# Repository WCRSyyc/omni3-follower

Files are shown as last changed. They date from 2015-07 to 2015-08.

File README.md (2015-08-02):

# 3 Omni Wheel line follower

Arduino sketch code for a 3 [Omni Wheel](https://en.wikipedia.org/wiki/Omni_Wheel) (also called Poly Wheel) based line follower robot.

The physical structure for the robot chassis is based on an equalateral triangle base, with a single wheel on each edge
The electronics are mounted on (somewhat smaller) triangular layers above the main base, and a bottom layer is hung
below the main chasis to hold the line follower sensors just above the floor.  The points of the chassis layer are
truncated, turning it into a six sided shape, with 3 long and 3 shorter edges.  Currently the bottom sensor layer is cut
to the same shape and size as the chassis layer, but it really only needs to be large enough to hold the circle of
downward sensors.  The mount points could be moved inside of the sensor circle.

This layout is more robust to variations in the driving surface than the [four omni wheel](https://github.com/WCRSyyc/omni4-follower)
robot.  With only 3 contact points, it can tilt to match surface contours, and maintain contact and traction on all wheels.

Spreadsheets are included in .xls and .ods formats with position and dimension information for the base and sensor levels.  A .dxf of file is also included, that was created from the spreadsheet information, then used to laser-cut the pieces.

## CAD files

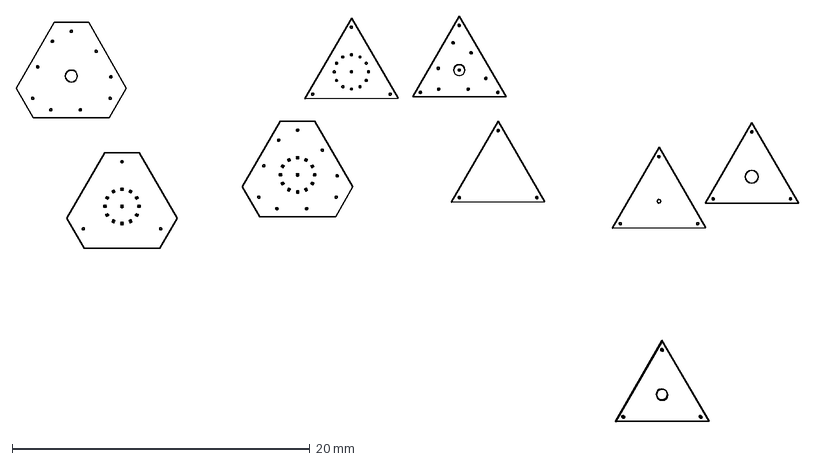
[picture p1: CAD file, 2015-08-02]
LineFollowerTemplates-Triangle.dxf
52.5 x 27.2 mm

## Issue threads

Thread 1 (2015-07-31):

Refactoring idea: separate the sensing and control logic

mMerlin, 2015-07-31:
The line follower has 2 quite distinct functional modules.  One reads the sensors to determine where the line is, and the other sends commands to the motors (servos) to move in the correct direction.  The functions have minimal overlap, and it should be possible to make them into modules or libraries.  This would make it easy to plug-and-play with different physical chassis configuration, and alternate sensor packages.

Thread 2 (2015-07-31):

Line following 'logic'

mMerlin, 2015-07-31:
A more **usual** line follower bot, with all of the sensors at the front, tends to start turning as soon as the line being followed moves off of center.  Or deliberately keeps turning back and forth to *sniff* for the edges of the line.  With the circle of sensors being used for this project, an alternative strategy might be more appropriate.  Whether it can be implemented or not is a separate issue to be explored :)

To start, I will define the line following goal to be to keep the sensor at the centre of the circle over the line.  That means the changes in direction can / need to be delayed from the time that the leading edge sensors detect the line moving away from the current direction of travel.  I say `line moving`, because from the perspective of the bot, and controlling code, that is what is happening.  The line **moves** away from the sensor that was detecting it, and the bot will need to *follow* the moving line.

With a straight line, and the bot aligned with, and centered over it, 3 sensors should see the line.  The middle point, plus one front (direction of travel) and one back sensor.  If the line stays straight, and the bot starts to stray from the line, the front sensor will loose the line, but the other 2 will still see it.  Same thing if the line curves, or does a shape bend.  The middle and back sensors will continue to see the line, when the leading sensor looses 'contact'.  With the goal of keeping the middle sensor on the line, no action is needed immediately for any of those cases.  The bot can maintain the current course, and wait to see where / how fast the line position is changing.  Only when the bots motion (based on known (although approximate) speed) brings it to the place where the middle sensor reaches (or almost reaches) the point where the leading sensor lost the line is a correction needed.  By that time, additional sensor readings should have provided enough information to make a pretty good guess at the local shape of the line.  This should allow accurate sharp turns that keep the middle sensor on the line.  It should also allow smoothly following a curved line, instead of continuously 'bouncing' off of the edges of the line.

Information that will need to be determined before implementation: For any direction of travel, how fast is the bot moving?  How fast can it change direction?  That is really, what does the acceleration look like for radical changes (90 degrees or more turn, maximum speed to 0 and back)?  Unless the acceleration is high enough to have a  negligible effect on positioning (relative to the errors from sensor measurements, and position uncertainty (relative to the line), that will need to be accounted for in the turn calculations.  It might even need explicit deceleration for sharp corners.

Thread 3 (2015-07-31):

Fails figure 8 line pattern

mMerlin, 2015-07-31:
The current code ends up following only one loop of the figure 8, instead of crossing over and following other loop.  At least somewhat dependent on the starting conditions.  The initial test correctly crossed the line intersection, but when it came around to the intersection again, it just circled on loop on that side.

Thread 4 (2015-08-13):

Interaction between power source and servo control on Mega

mMerlin, 2015-08-13:
Well that was interesting/frustrating/different.  There seems to be some sort of interaction between what power source is used for the Mega2560 and servo control.

This **should** not be a servo power problem for (at least) 2 reasons.
1) in both cases the servos are powered through a separate power regulator
2) half of the servo range works, and the other half should need the same power

I was setting up to do some calibration / profiling of the servos for the line follower for the museum display, and was getting strange results.  So I wrote a new test script that just exercises the servos based on the Sweep example sketch.  That did not work either, so I reloaded the original line-follower sketched, and tried that with the test track.  That worked normally.  Finally I tried my test sketch powered by the on board regulator instead of through the usb cable.  That seemed to work, but of course no debug output without the usb cable and Serial.print().  So I cut my test program down even more to make sure Serial was not causing the problem.  Same symptoms.  Powered by USB only the low range servo.write() worked.  The high value (180) acts about the same as 90.

Summary: With the Mega hooked up (only) to, and powered by, a usb cable, only Servo.write() 0 through 90 seems to be working correctly.  Higher values act about like 90, or jitter, or turn the servo very slowly in the opposite direction (from the low values).  When the usb cable is removed, and the Mega is powered through the on board regulator, the full range of servo.write() works.  I also tested using servo.writeMicroseconds() with the same results.  Only the lower half of the range works when powered through usb.

I have minimal tools at home.  If we get time on Saturday, I'll see about putting a scope on some of the voltages/signals, to see if there is an obvious difference.

I’m open to ideas about what could cause the observed symptoms.

For reference, here is the simple test sketch with everything deliberately hard-coded. write(180) does not work (only) when powered through usb.
```c
void setup()
{
  // Serial.begin(9600);
  myservoA.attach(22);
  myservoB.attach(23);
  myservoC.attach(24);
  myservoA.write(90);
  myservoB.write(90);
  myservoC.write(90);
}

void loop()
{
  // Serial.println("full forward");
  myservoA.write(180);
  myservoB.write(180);
  myservoC.write(180);
  delay(5000);
  myservoA.write(90);
  myservoB.write(90);
  myservoC.write(90);
  delay(1000);
  // Serial.println("full backward");
  myservoA.write(0);
  myservoB.write(0);
  myservoC.write(0);
  delay(5000);
  myservoA.write(90);
  myservoB.write(90);
  myservoC.write(90);
  delay(1000);
}
```

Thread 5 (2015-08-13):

servo profiling

mMerlin, 2015-08-13:
If the previous issue #4 can not be resolved, and alternate method of collecting the profile information is needed.  The current physical build of the line follower does not have any way of directly reporting information without a usb cable.

## Ideas
* Connected another Arduino board, and setup a serial pass-thru sketch, So the mega can use Serial.print to send to the 2nd board, which echos the content to its on usb connected serial line.
* The bot has 13 LED's for displaying sensor / status information.  13 bits is enough to report settings and timing results.
* The servo rotation sensor can be attached to the second Arduino board, and the timing done there.  That was actually the way the initial testing (of the rotation sensor) was done.  This would need a way to control the state (servo speed) changes on the Mega.  That could (again) be a direct serial connection, but even a single digital pin would be enough to cycle through the states

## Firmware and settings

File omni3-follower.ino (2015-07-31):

//  Line_Follower_Display_Tripod_150725

//  Direction coordinates in Direction subroutine programmed according to paper obtained at this site:
//  http://www.researchgate.net/publication/228786543_Three_omni-directional_wheels_control_on_a_mobile_robot
//  Some fine tuning was required, due to differences between the three servos

#define SIZE 14
#define CUTOFF 150
#include <Servo.h>
Servo myservoA; 
Servo myservoB;  
Servo myservoC;
int TRUE = HIGH;
int FALSE = LOW;
int black;
int blacks = 0;
int CENTER = 13;
int find = 0;
int i = 0;
int inside = 0;
int loops = 0;
int outside = 0;
int STOP = 15;
int quit = FALSE;
long time;
long time0;
int ledPins[SIZE] = {0,31,32,33,34,35,36,37,38,39,40,41,42,43};
int lightLevel[SIZE] = {0,1,2,3,4,5,6,7,8,9,10,11,12,13};
int list[37] = {0,1,2,3,4,5,6,7,8,9,10,11,12,1,2,3,4,5,6,7,8,9,10,11,12,1,2,3,4,5,6,7,8,9,10,11,12};

void setup() {
  Serial.begin(9600);
  myservoA.attach(22);  
  myservoB.attach(23);
  myservoC.attach(24);
  Direction(STOP);
  for (int i = 1; i < SIZE; i++) {
    pinMode(lightLevel[i], INPUT);
    pinMode(ledPins[i], OUTPUT);
    digitalWrite(ledPins[i], LOW);
  }
  for (int i = 1; i < 4; i++) {
    digitalWrite(ledPins[1], HIGH);
    delay (200);
    digitalWrite(ledPins[1], LOW);
    delay (200);
  }
  digitalWrite(ledPins[1], HIGH);
  delay (3000);
  scan();
  time = millis();
  Serial.println(" ");
  Serial.println ("Point 0 - start");
  Serial.print("time = ");
  Serial.println(time);
  sensors ();
  //
  // find start point
  //
  find = 0;
  time0 = millis();
  do {
    Direction(4);
    if (analogRead(CENTER) > CUTOFF && find == 0) {
      find = 1;
    }
    else if (analogRead(CENTER) < CUTOFF && find == 1) {
      find = 2;
      i = 1;
    }
  }
  while (find != 2 && millis() - time0 < 3000);
  if (find !=2){
    find = 0;
    do {
      Direction(10);
      if (analogRead(CENTER) > CUTOFF && find == 0) {
        find = 1;
      }
      else if (analogRead(CENTER) < CUTOFF && find == 1) {
        find = 2;
        i = 7;
      }
    }
    while (find != 2);
  }
  Direction(STOP);
  delay(5);
  Serial.println (" ");
  Serial.println("Point 1 - moved into position, find initial inside outside");
  scan();
  sensors();
  
//
// find inside
//
  quit = FALSE;
  do {
    if (lightLevel[list[19-i]] < CUTOFF) {
      inside = list[19-i];
      i = i + 1;
    }
    else {
      quit = TRUE;
    }    
  }
  while (quit == FALSE);
  outside = list[inside+9];
  Serial.print("inside = ");
  Serial.println(inside);
  Serial.print("outside = ");
  Serial.println(outside);
}
//---------------------------------end of Void Setup----------------------------------

void loop () {
  //
  // Move inside direction
  //
  loops =  0;
  if (analogRead(outside) < CUTOFF && analogRead(CENTER) < CUTOFF) {
    Direction(inside);
    lightLevel[outside] = analogRead(outside);
    lightLevel[CENTER] = analogRead(CENTER);
    while (lightLevel[outside] < CUTOFF && lightLevel[CENTER] < CUTOFF) {
      lightLevel[outside] = analogRead(outside);
      lightLevel[CENTER] = analogRead(CENTER);
      loops = loops + 1;
    }
  }
  Direction(STOP);
  Serial.println(" ");
  Serial.print("lightLevel[outside] = ");
  Serial.println(lightLevel[outside]);
  Serial.print("lightLevel[CENTER] = ");
  Serial.println(lightLevel[CENTER]);
  Serial.println("Point 2 - moved inside direction - normal move");
  Serial.print("loops = ");
  Serial.println(loops);
  //
  // Move outside direction
  //
  loops = 0;
  if (analogRead(CENTER) < CUTOFF) {
    Direction(outside);
    while (analogRead(CENTER) < CUTOFF) {
      loops = loops + 1;
    }
  }
  Direction(STOP);
  Serial.println(" ");
  Serial.println ("Point 3 - moved outside direction - normal move");
  Serial.print("loops = ");
  Serial.println(loops);
  scan();
  sensors();
  //
  // find new inside and outside
  //
  findInsideOutside();
  loops = 0;
  if (analogRead(CENTER) >= CUTOFF) {
    Direction(list[inside+1]);
    while (analogRead(CENTER) >= CUTOFF) {
      loops = loops + 1;
    }
    Serial.println(" ");
    Serial.println ("Point 4 - moved CENTER off line");
    Serial.print("loops = ");
    Serial.println(loops);
    scan();
    sensors();
  }
}
//---------------------------------end of void loop----------------------------------

    
void Direction (int x) {
  switch (x) {
  case 1:
    digitalWrite(ledPins[1], HIGH);
    myservoA.write(82.98);     
    myservoB.write(97);
    myservoC.write(90);
    break;
    
  case 2:
    digitalWrite(ledPins[2], HIGH);
    myservoA.write(87);     
    myservoB.write(97);
    myservoC.write(86.6);
    break;
  
  case 3:
    digitalWrite(ledPins[3], HIGH);
    myservoA.write(90);     
    myservoB.write(97);
    myservoC.write(83.2);
    break;
  
  case 4:
    digitalWrite(ledPins[4], HIGH);
    myservoA.write(93.4);     
    myservoB.write(93.7);
    myservoC.write(83.2);
    break;
  
  case 5:
    digitalWrite(ledPins[5], HIGH);
    myservoA.write(97.02);     
    myservoB.write(90);
    myservoC.write(83.2);
    break;
  
  case 6:
    digitalWrite(ledPins[6], HIGH);
    myservoA.write(97.02);     
    myservoB.write(87.2);
    myservoC.write(87.2);
    break;
  
  case 7:
    digitalWrite(ledPins[7], HIGH);
    myservoA.write(97.02);     
    myservoB.write(83);
    myservoC.write(90);
    break;
  
  case 8:
    digitalWrite(ledPins[8], HIGH);
    myservoA.write(93);     
    myservoB.write(83);
    myservoC.write(93.4);
    break;
  
  case 9:
    digitalWrite(ledPins[9], HIGH);
    myservoA.write(90);     
    myservoB.write(83);
    myservoC.write(96.8);
    break; 
  
  case 10:
    digitalWrite(ledPins[10], HIGH);
    myservoA.write(87);     
    myservoB.write(86.9);
    myservoC.write(97.2);
    break; 
  
  case 11:
    digitalWrite(ledPins[11], HIGH);
    myservoA.write(82.98);     
    myservoB.write(90);
    myservoC.write(96.8);
    break;
  
  case 12:
    digitalWrite(ledPins[12], HIGH);
    myservoA.write(82.98);     
    myservoB.write(93.5);
    myservoC.write(93.5);
    break;
    
  case 15:
    myservoA.write(90);     
    myservoB.write(90);
    myservoC.write(90);
    break;
 
  default:
    Serial.println ("No Case Found In Direction");
  }
} 

//---------------------------------end of Direction----------------------------------

void findInsideOutside() {
  //
  // FIND NEAREST blacks
  //
  if (lightLevel[inside] >= CUTOFF) {
    black = inside;
  }
  else if (lightLevel[list[inside+1]] >= CUTOFF){
    black = list[inside+1];
  }
  else if (lightLevel[list[inside+11]] >= CUTOFF){
    black = list[inside+11];
  }
  else if (lightLevel[list[inside+2]] >= CUTOFF){
    black = list[inside+2];
  }
  else if (lightLevel[list[inside+10]] >= CUTOFF){
    black = list[inside+10]; 
  }
  else if (lightLevel[list[inside+3]] >= CUTOFF){
    black = list[inside+3];
  }
  else if (lightLevel[list[inside+9]] >= CUTOFF){
    black = list[inside+9];
  }
  else if (lightLevel[list[inside+4]] >= CUTOFF){
    black = list[inside+4];
  }
  else if (lightLevel[list[inside+8]] >= CUTOFF){
    black = list[inside+8];
  }
  else if (lightLevel[list[inside+5]] >= CUTOFF){
    black = list[inside+5];
  }
  else if (lightLevel[list[inside+7]] >= CUTOFF){
    black = list[inside+7];
  }
  else if (lightLevel[list[inside+6]] >= CUTOFF){
    black = list[inside+6];
  }
  else {
    Direction(STOP);
  }
  for (i = 1; i < 12; i++){
    if (lightLevel[list[black + i]] < CUTOFF){
      inside = list[black + i];
      break;
    }  
  }
  outside = list[inside+9];
  Serial.println(" ");
  Serial.print("inside = ");
  Serial.println(inside);
  Serial.print("outside = ");
  Serial.println(outside);
}
//---------------------------------end of findInsideOutside-------------------------

void scan () {
  for (int i = 1; i < SIZE; i++) {
    digitalWrite(ledPins[i], LOW);
    lightLevel[i] = analogRead(i);
  }
}

//---------------------------------end of Scan---------------------------------------

void sensors () {
  blacks = 0;
  for (int i = 1; i < SIZE; i++) {
    if (lightLevel[i] > CUTOFF) {
      blacks = blacks + 1;
    }
  Serial.print(lightLevel[i]);
  Serial.print(", ");
  }
  Serial.println(" ");
  Serial.print("Number of blacks = ");
  Serial.println(blacks);
  for (int i = 1; i < SIZE; i++) {
    if (lightLevel[i] > CUTOFF) {
      Serial.print(i);
      Serial.print(", ");
    }
  }
  Serial.println(" ");
}
//---------------------------------end of sensors------------------------------------
